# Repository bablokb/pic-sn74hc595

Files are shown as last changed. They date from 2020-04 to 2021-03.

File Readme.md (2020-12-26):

SN74HC595 based debugger for the PIC12F675
==========================================

This project provides a simple "debugger" based on the SN74HC595
shift-register. In this scenario the pic needs two GPs to clock out
data to the shift-register IC. Connecting eight leds to the IC you
can display whole bits. If you chain two 595 together, you can display
16 bit words.

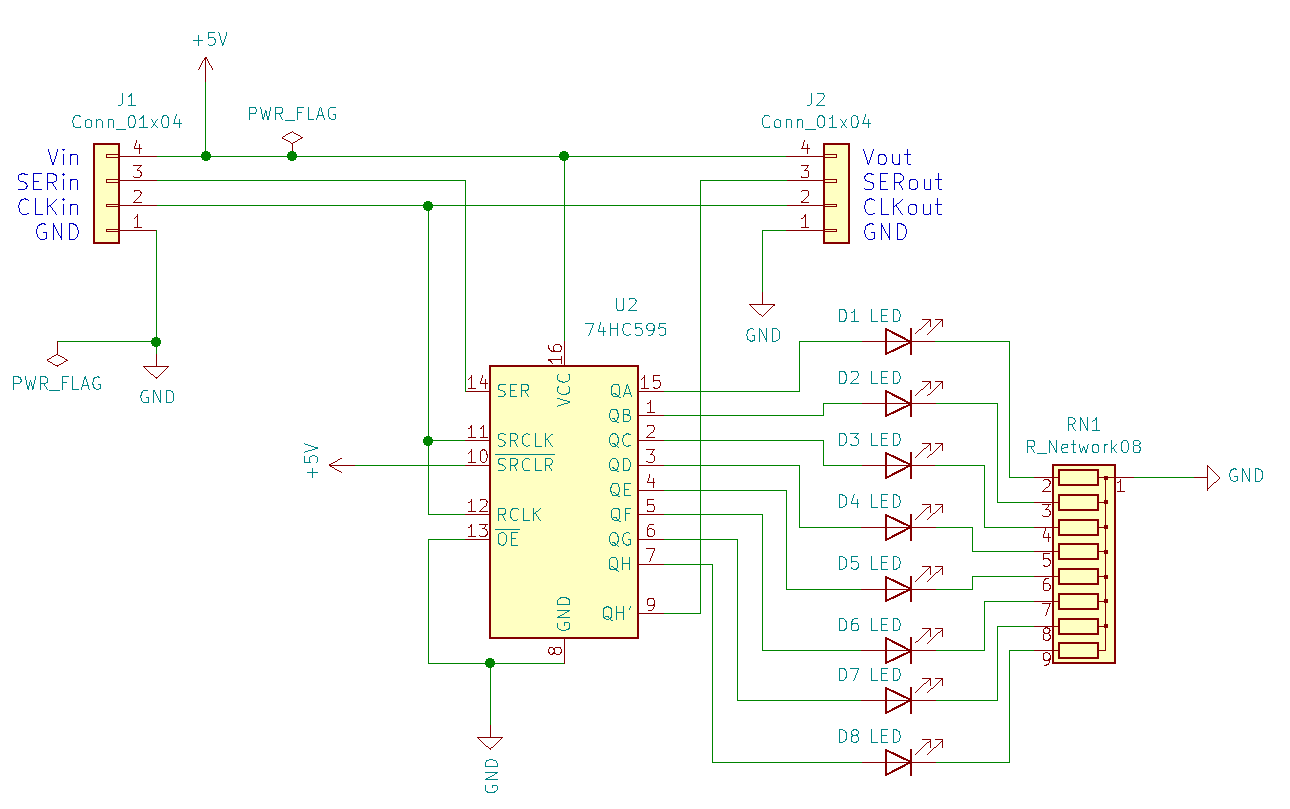
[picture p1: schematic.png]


To save a GP-line, we don't bother to clock out from serial-register
to parallel-register. Instead we connect SRCLK and RCLK. This needs an
additional clock-cycle for the last bit, i.e. the pic sends 9 bits
in total. With two connected 595-ICs, the pic sends 17 bits.

The example program waits for a button-press on GP5 and then displays
and increasing counter. It stops again once the counter wraps around to
zero or if the button is pressed again.

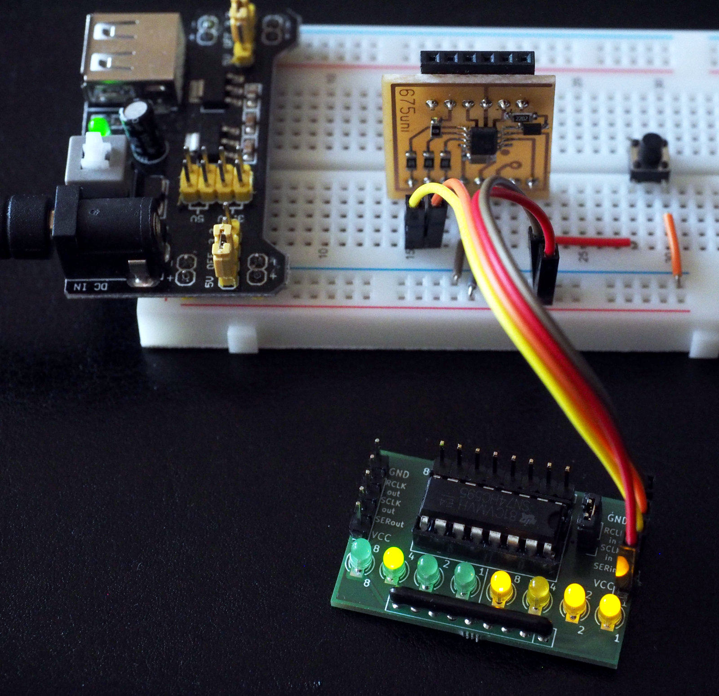
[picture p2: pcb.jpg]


The KiCAD source of the pcb is in the directory `sn74hc595_dbg.kicad`. The
library and the example application is in the directory `src`. Note that
you need sdcc and gputils to compile and link the files, but porting
to a different toolchain should be simple.

You also need the header-files and makefile rules of my
[pic-toolchain](https://github.com/bablokb/pic-toolchain)-project.

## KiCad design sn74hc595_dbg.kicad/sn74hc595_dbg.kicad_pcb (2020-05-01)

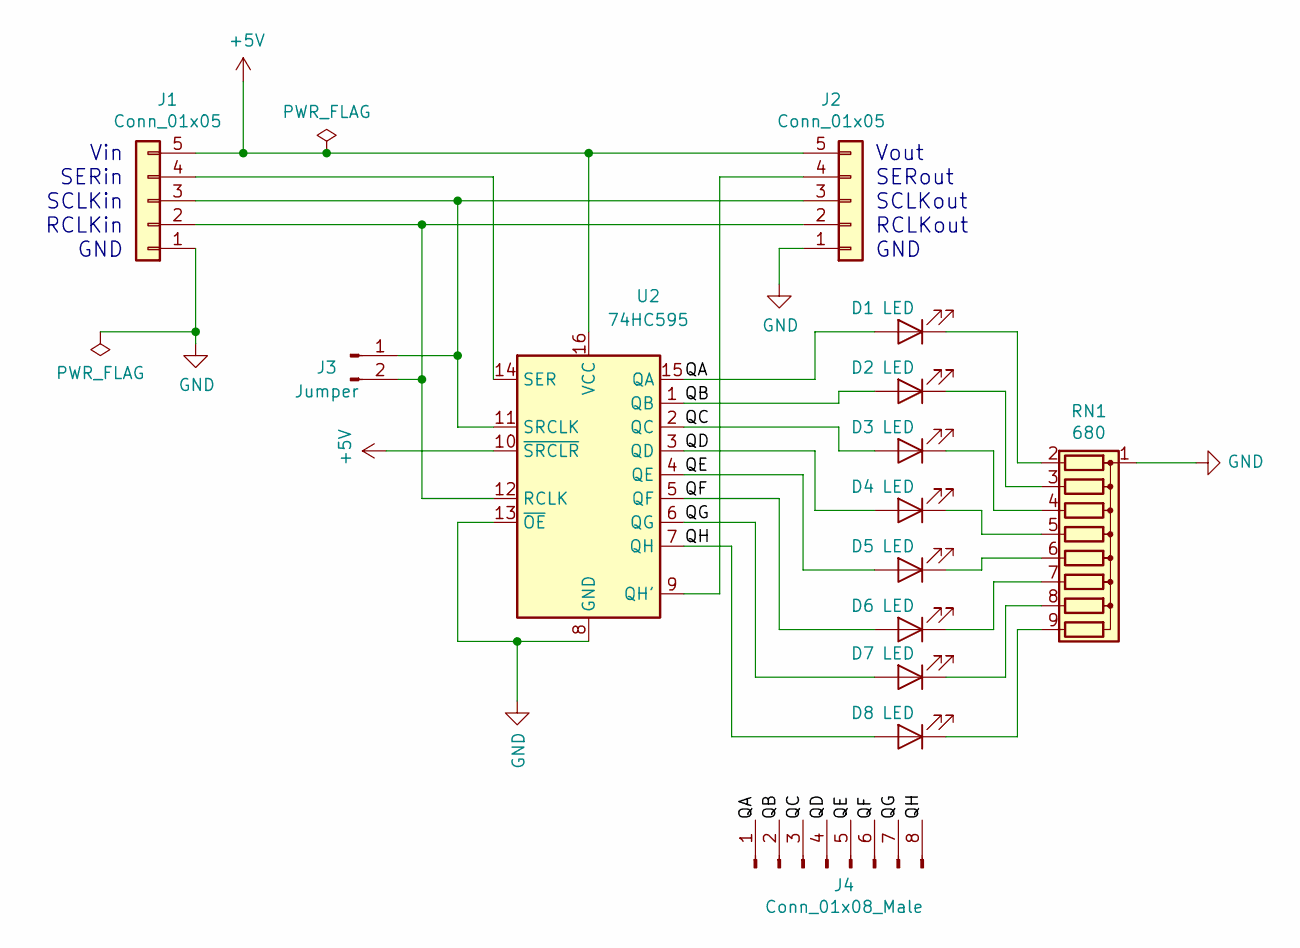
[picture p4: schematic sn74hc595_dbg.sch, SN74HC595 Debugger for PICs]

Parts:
D1, D2, D3, D4, D5, D6, D7, D8: LED; LED_D3.0mm
J1, J2: Conn_01x05; PinHeader_1x05_P2.54mm_Vertical
J3: Jumper; PinHeader_1x02_P2.54mm_Vertical
J4: Conn_01x08_Male; PinHeader_1x08_P2.54mm_Vertical
RN1: 680; R_Array_SIP9
U2: 74HC595; DIP-16_W7.62mm_Socket

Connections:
+5V: J1.5, J2.5, U2.10 (~SRCLR), U2.16 (VCC)
/QA: D1.2 (A), J4.1, U2.15 (QA)
/QB: D2.2 (A), J4.2, U2.1 (QB)
/QC: D3.2 (A), J4.3, U2.2 (QC)
/QD: D4.2 (A), J4.4, U2.3 (QD)
/QE: D5.2 (A), J4.5, U2.4 (QE)
/QF: D6.2 (A), J4.6, U2.5 (QF)
/QG: D7.2 (A), J4.7, U2.6 (QG)
/QH: D8.2 (A), J4.8, U2.7 (QH)
GND: J1.1, J2.1, RN1.1 (common), U2.8 (GND), U2.13 (~OE)
unnamed: D1.1 (K), RN1.2 (R1)
unnamed: D2.1 (K), RN1.3 (R2)
unnamed: D3.1 (K), RN1.4 (R3)
unnamed: D4.1 (K), RN1.5 (R4)
unnamed: D5.1 (K), RN1.6 (R5)
unnamed: D6.1 (K), RN1.7 (R6)
unnamed: D7.1 (K), RN1.8 (R7)
unnamed: D8.1 (K), RN1.9 (R8)
unnamed: J1.2, J2.2, J3.2, U2.12 (RCLK)
unnamed: J1.3, J2.3, J3.1, U2.11 (SRCLK)
unnamed: J1.4, U2.14 (SER)
unnamed: J2.4, U2.9 (QH')

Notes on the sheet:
Vin SERin SCLKin RCLKin GND
Vout SERout SCLKout RCLKout GND

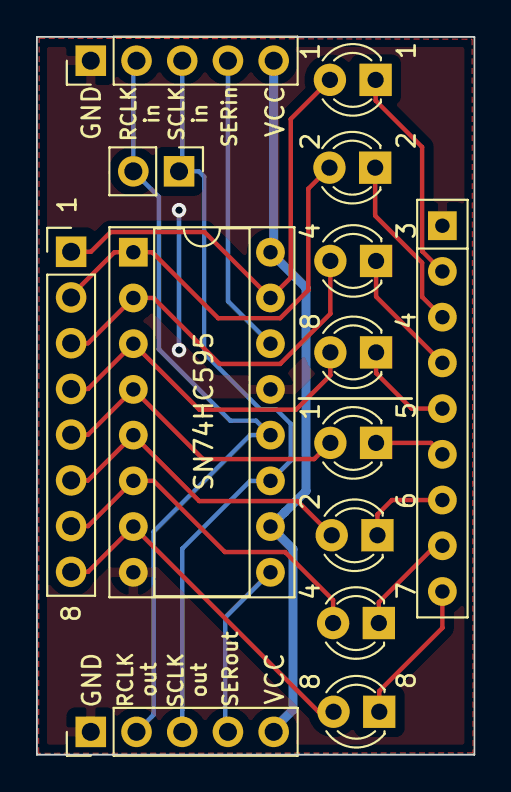
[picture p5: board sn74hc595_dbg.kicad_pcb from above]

Board: 2 copper layers, 24.3 x 39.9 mm, 14 parts (0 on the bottom side), 22 nets.

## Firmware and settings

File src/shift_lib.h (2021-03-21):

// --------------------------------------------------------------------------
// SN74HC595 driver
//
// Author: Bernhard Bablok
// https://github.com/bablokb/pic-sn74hc595
//
// --------------------------------------------------------------------------

#ifndef __SHIFT_LIB_H
  #define __SHIFT_LIB_H

  #include "picconfig.h"
  #include <stdint.h>

// Define Pins
#ifndef PIN_SR_CLK
  #define PIN_SR_CLK 1
#endif
#define GP_CLK     _CONCAT(RA,PIN_SR_CLK)      // Serial clock pin

#ifndef PIN_SR_DATA
  #define PIN_SR_DATA 2
#endif
#define GP_DATA    _CONCAT(RA,PIN_SR_DATA)     // Serial data pin

  // Function Declarations
  void so_init(void);
  #ifdef SO_BYTE
    void so_byte(uint8_t data);
    #define so_clear() so_byte(0x00)
  #endif
  #ifdef SO_ADDR
    void so_addr(uint16_t data);
    #define so_clear() so_addr(0x00)
  #endif
#endif

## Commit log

2020-04-19 Rev 1: initial commit
    [sn74hc595_dbg.kicad_pcb, sn74hc595_dbg.sch]
2020-04-20 swapped horizontal LEDs with vertical LEDs
    [sn74hc595_dbg.kicad_pcb, sn74hc595_dbg.sch]
2020-04-20 optimized layout, added labels
    [sn74hc595_dbg.kicad_pcb]
2020-04-30 Rev 2: connector for output-pins / jumper for SCLK/RCLK connection
    [sn74hc595_dbg.kicad_pcb, sn74hc595_dbg.sch]
2020-05-01 optimized labels
    [sn74hc595_dbg.kicad_pcb]
2020-05-10 fixed link to github-repository
    [shift_lib.h]
2020-05-19 link to pcb.jpg
2020-09-29 renamed pin-names
2020-09-29 define default pin-numbers
2020-10-14 make GP for button configurable / fix small bugs
2020-11-20 swapped default pin-allocation
